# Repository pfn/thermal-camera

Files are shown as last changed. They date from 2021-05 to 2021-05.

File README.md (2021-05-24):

# DIY Thermal Camera #

This is a simple thermal camera that can be built using off-the-shelf parts
from Adafruit (albeit with a long lead time due to component shortages).

[Reddit post about it](https://www.reddit.com/r/functionalprint/comments/nfmj6n/diy_thermal_camera/)

## BOM ##

* [Adafruit 1.3" PiTFT Bonnet](https://www.adafruit.com/product/4506)
* [Raspberry Pi Zero W](https://www.adafruit.com/product/3400)
  * You'll want with headers if you don't have any you can solder yourself
* [MLX90640 IR Thermal Camera](https://www.adafruit.com/product/4407)
* [MicroSD card](https://www.adafruit.com/product/2820)
* [StemmaQT cable](https://www.adafruit.com/product/4210)

## Features ##

* Auto-start at boot
  * This software runs on a Raspberry Pi Zero W, as a result it needs to boot.
    When it boots, it automatically starts up via systemd
* Freeze frame
  * Pause capturing to examine the current frame, all view settings can be
    manipulated to look at individual pixel temperatures, adjust corrections,
    scales, etc.
* Capture to PNG
  * Saves images to `~pi/thermal-images`
* MTP support for transferring images
  * Exposes `~pi/thermal-images` over MTP for Windows,
    macOS (Android File Transfer) and Linux machines
* Selectable temperature ranges
  * Available temperature ranges are: auto-range (min, max),
    outdoor body detection (10-32C), indoor body detection (20-32C), hot spot
    identification (20-50C), and extremes (-10 - 200C)
* Switchable C/F temperature scale
* Adjustable emissivity correction
  * Adjustable from 0.05 to 1.00 in 0.05 increments. Default at 0.95
* Movable reticle showing temperature under the crosshairs
* Four lockable reticle points for indicating temperature
  * Temperature at 7 points can be tracked in real time: under the reticle, at
    the four locked reticle points, and the min and max points
* Switchable color range (Gnuplot PM3D, and a basic rainbow)
* Display of estimated ambient temparture
  * This can be warmer than ambient, depending on the temperature of the Pi
    inside the case.

### Controls ###

* Hold A (left button) and then B (right) together at the same time to exit
* Hold B and then A together at the same time to change the scale palette
  to PM3D or rainbow
* Press A by itself to freeze-frame, press again to release freeze-frame
* Press B by itself to toggle the temperature units between C and F
* Press U(p), L(eft), R(ight), D(own) by themselves to move the center reticle
* Hold B and press U to adjust emissivity correction up by 0.05
* Hold B and press D to adjust emissivity correction down by 0.05
* Hold B and press L or R to scroll through temperature ranges
* Press C(enter) by itself to lock a reticle location for temperature readout
* Hold B and press C to clear all selected reticle locations
* Hold A and press C to save the current screen to disk as PNG

## Instructions ##

This solution involves installing software from raspbian packages, python3
packages using `venv` and `pip`, and some locally compiled components
[uMTP-Responder](https://github.com/viveris/uMTP-Responder)

In addition to software, there is minimal hardware assembly and 3D printed
parts.

### Software ###

* $ `sudo apt install python3-venv`
* $ `python3 -m venv --system-site-packages ~/src/thermal-imaging`
* $ `cd ~/src && git clone https://github.com/pfn/thermal-camera thermal-imaging`
* $ `cd ~/src/thermal-imaging/bin`
* $ `./pip install ST7789`
* $ `./pip install mlx90640-driver`
* $ `./pip install mlx90640-driver-devicetree`
* $ `./pip install colour`
* $ `./pip install pillow`
* $ `./pip install RPi.GPIO`
* $ `sudo mkdir /etc/umtprd`
* $ `sudo cp ../conf/umtprd.conf /etc/umtprd/`
* $ `sudo cp ../conf/thermal-camera.service /etc/systemd/system/`
* $ `sudo cp ../conf/umtp-responder.service /etc/systemd/system/`
* $ `ln -s armv7l ../lib/python3.7/site-packages/mlx90640/libs/armv6l`
* $ `ln -s armv7l ../lib/python3.7/site-packages/mlx90640_devicetree/libs/armv6l`
* $ `cd ~/src && git clone https://github.com/viveris/uMTP-Responder`
* $ `cd uMTP-Responder && make`
* Add `dtoverlay=dwc2` to the bottom of `/boot/config.txt`
* $ `sudo systemctl enable thermal-camera`
* $ `sudo systemctl enable umtp-responder`
* Reboot the Pi

For any missing packages, `sudo apt install` them as appropriate.

### Hardware ###

Print 2x of the buttons, 4x of the spacers, the top and bottom of the case.

Solder headers onto the Pi if necessary.

Attach the StemmaQT cable to the camera and TFT bonnet.

Place the Pi into the bottom of the case. And place the 4 spacers onto the
nubs that protrude through the Pi.

Press the TFT bonnet down into place onto the Pi.

Position the camera on the bottom of the case and place the lens through the
hole.

Put the top of the case onto a flat surface, and put the buttons into the
button holes.

Run a bead of super glue around the edges and press the case together.

All done!

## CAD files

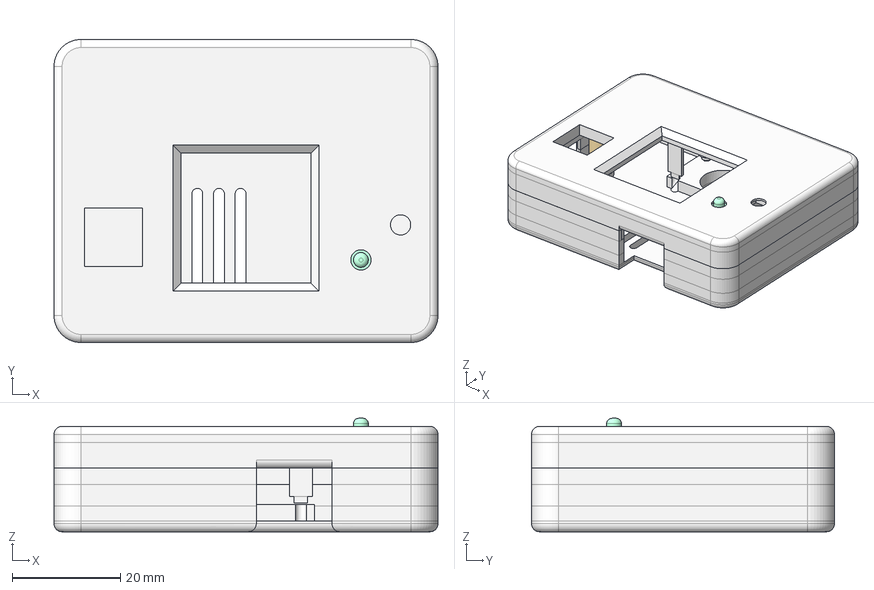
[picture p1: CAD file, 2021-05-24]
CAD/Case Design.step
71.0 x 56.0 x 21.0 mm
Top
Bottom
Standoffs
Buttons

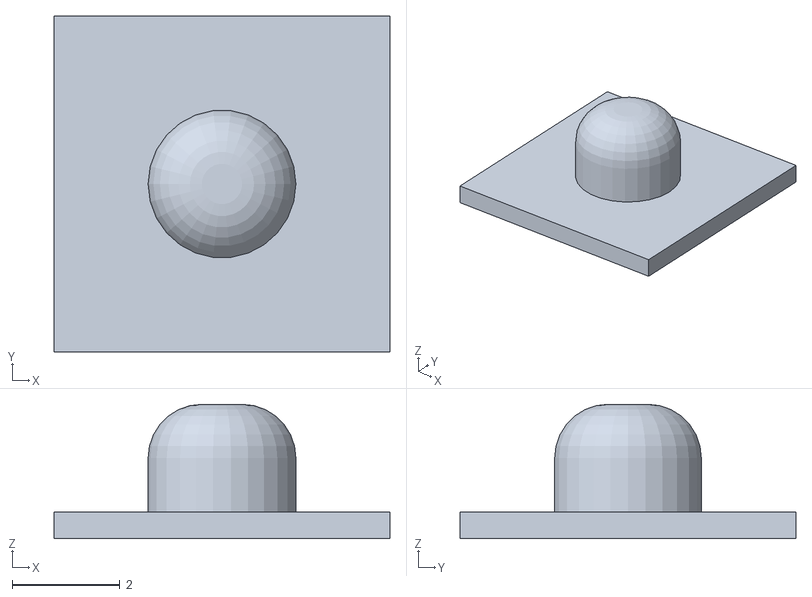
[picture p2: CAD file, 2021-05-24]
models/Button.stl
6.25 x 6.25 x 2.50

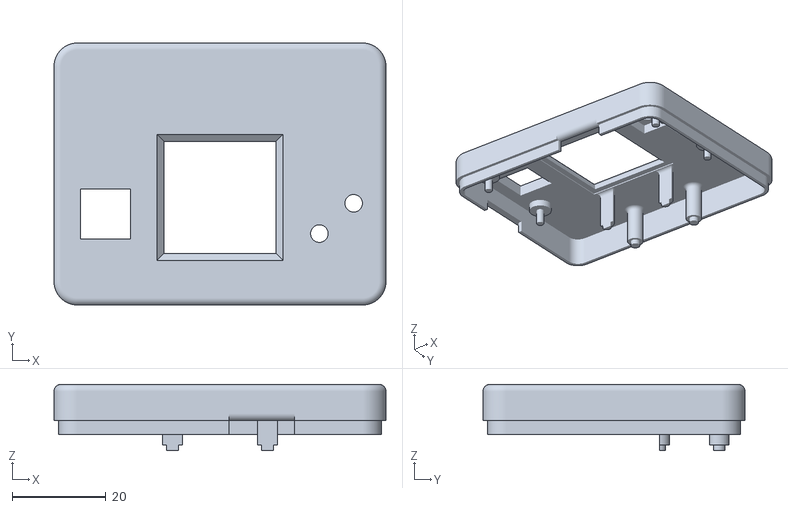
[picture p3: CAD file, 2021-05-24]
models/Case Top.stl
71.0 x 56.0 x 14.2

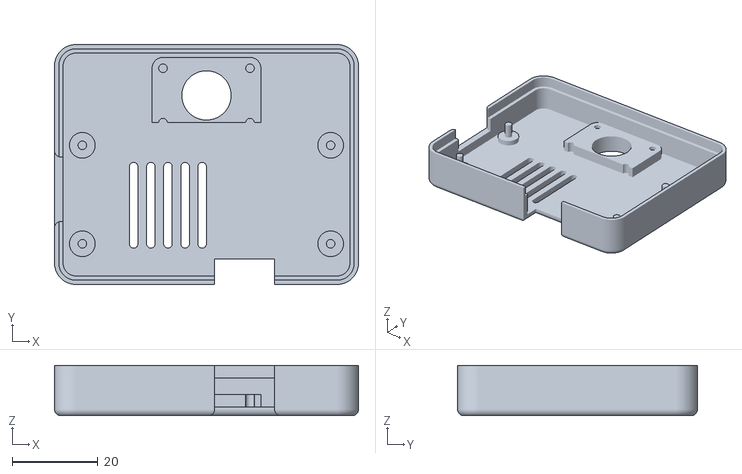
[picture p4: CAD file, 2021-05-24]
models/Case Bottom.stl
71.0 x 56.0 x 11.8

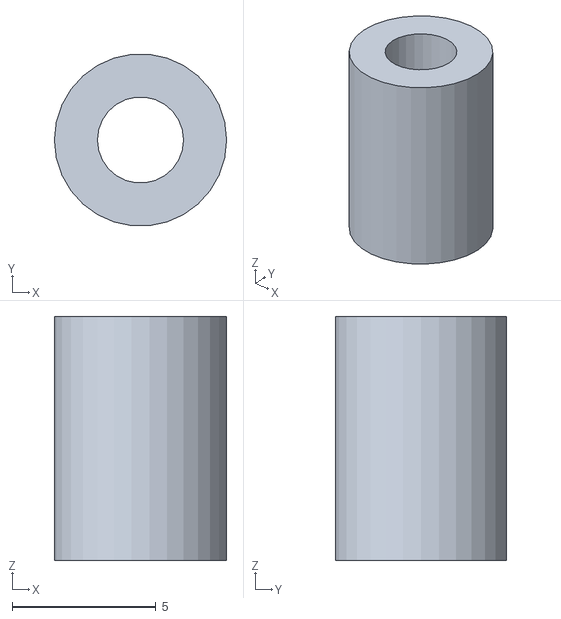
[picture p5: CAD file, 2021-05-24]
models/Standoff.stl
6.00 x 5.97 x 8.50

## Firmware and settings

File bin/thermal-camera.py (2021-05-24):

#!/home/pi/src/thermal-imaging/bin/python

save_path = "/home/pi/thermal-images"

# Imports take a while to execute, so interleave them as used
import os

import ST7789 as ST7789
disp = ST7789.ST7789(
  port=0,
  cs=ST7789.BG_SPI_CS_BACK,  # BG_SPI_CS_BACK or BG_SPI_CS_FRONT
  dc=25,
  backlight=26,               # 18 for back BG slot, 19 for front BG slot.
  spi_speed_hz=80 * 1000 * 1000,
  offset_left=0
)
disp.begin()
width = disp.width
height = disp.height

from PIL import Image, ImageDraw, ImageFont
image = Image.new("RGB", (width, height))
draw = ImageDraw.Draw(image)

def clear_screen(f=(0, 0, 0)):
    draw.rectangle((0, 0, width, height), outline=f, fill=f)
    disp.display(image)

clear_screen((0, 255, 255))

font_name = "/usr/share/fonts/truetype/dejavu/DejaVuSans.ttf"
FH = 16
fnt = ImageFont.truetype(font_name, FH)
caretfnt = ImageFont.truetype(font_name, FH * 2)
WHITE = (255, 255, 255)
line_number = 0

def init_text(text):
    global line_number
    draw.text((5, 5 + line_number * (FH + 2)), text, font=fnt, fill=WHITE)
    line_number += 1
    disp.display(image)

clear_screen()
init_text("Display initialized")

import RPi.GPIO as GPIO

import mlx90640
dev = mlx90640.MLX90640()
dev.i2c_init("/dev/i2c-1")
dev.set_refresh_rate(4)

init_text("Camera found")

# auto, FLIR default, indoor mammals, hot spots, extremes
ranges = ((0.0, 0.0), (10.0, 32.22),
        (20.0, 32.0), (20.0, 50.0), (-10.0, 200.0))

# globals used by button_press callback
freeze_frame = False
temp_range = 0
chordA = False
chordB = False
isF = False
emissivity = 0.95 # emissivity correction
reticle = int(768 / 2 - 16)
selected = list() 

import re
file_pattern = re.compile(r"image(\d{4}).png")

import functools
flatmap = lambda f, xs: [y for ys in xs for y in f(ys)]

def image_ordinal(f):
    if not os.path.isfile(os.path.join(save_path, f)):
        return ()
    m = re.match(file_pattern, f)
    return [int(m.group(1))] if m is not None else ()

def next_ordinal():
    return max([0] +
            [x for x in flatmap(image_ordinal, os.listdir(save_path))]) + 1

def save_image():
    global saving
    global is_dirty
    os.makedirs(save_path, exist_ok=True)
    saving = True
    is_dirty = False
    image.save("%s/image%04d.png" % (save_path, next_ordinal()))
    saving = False

colors = []
scale = []

# button pin assignments
A = 5
B = 6
L = 27
R = 23
U = 17
D = 22
C = 4
def button_press(x):
    global chordA
    global chordB
    global isF
    global emissivity
    global reticle
    global selected
    global temp_range
    global freeze_frame
    global is_dirty
    global scale
    global colors

    if not (x == A and chordA or x == B and chordB):
        is_dirty = True

    if x == A and not chordA:
        if GPIO.input(B) == 0:
            chordB = True
            colors = pm3d_colors if colors is not pm3d_colors else rainbow_colors
            scale = pm3d_scale if scale is not pm3d_scale else rainbow_scale
        else:
            freeze_frame = not freeze_frame
    else:
        chordA = False

    if x == B and not chordB:
        if GPIO.input(A) == 0:
            chordA = True
            clear_screen()
            disp.set_backlight(0)
            exit()
        else:
            isF = not isF
    else:
        chordB = False

    if x == U:
        if GPIO.input(B) == 0:
            chordB = True
            emissivity = min(emissivity + 0.05, 1.00)
        else:
            reticle = max(reticle - 32, 0)
    if x == D:
        if GPIO.input(B) == 0:
            chordB = True
            emissivity = max(emissivity - 0.05, 0.05)
        else:
            reticle = min(reticle + 32, 768)
    if x == L:
        if GPIO.input(B) == 0:
            temp_range = max(0, temp_range - 1)
            chordB = True
        else:
            reticle = min(reticle + 1, 768)
    if x == R:
        if GPIO.input(B) == 0:
            temp_range = min(len(ranges) - 1, temp_range + 1)
            chordB = True
        else: 
            reticle = max(reticle - 1, 0)
    if x == C:
        if GPIO.input(B) == 0:
            chordB = True
            if freeze_frame:
                # capture image to disk
                pass
            else:
                selected = []
        elif GPIO.input(A) == 0:
            chordA = True
            save_image()
        else:
            if reticle in selected:
                selected.remove(reticle)
            else:
                selected.append(reticle)
            while len(selected) > 4:
                del selected[0]

GPIO.setmode(GPIO.BCM)
for pin in [A, B, L, R, U, D, C]:
    GPIO.setup(pin, GPIO.IN)
    GPIO.add_event_detect(pin, GPIO.RISING)
    GPIO.add_event_callback(pin, button_press)

init_text("Buttons configured")

import math
def pm3d(steps):
    def _pm3d(x):
        r = round(255 * math.sqrt(x))
        g = round(255 * math.pow(x, 3))
        b = round(255 * max(math.sin(2 * math.pi * x), 0))
        return (int(r) | int(g) << 8 | int(b) << 16)
    return [x for x in map(lambda _x: _pm3d(_x / steps), range(0, steps))]

from colour import Color
rainbow_colors = list(Color('indigo').range_to(Color('red'), 256))
rainbow_colors = [(int(c.red * 255) | int(c.green * 255) << 8 |
    int(c.blue * 255) << 16) for c in rainbow_colors]
pm3d_colors = pm3d(256)

rainbow_scale = list(Color('red').range_to(Color('indigo'), 144 - 2 * FH - 4))
rainbow_scale = [(int(c.red * 255) | int(c.green * 255) << 8 |
    int(c.blue * 255) << 16) for c in rainbow_scale]

pm3d_scale = pm3d(144 - 2 * FH - 4)
pm3d_scale.reverse()

scale = pm3d_scale
colors = pm3d_colors

init_text("Palettes initialized")

def is_autorange():
    return ranges[temp_range][0] == ranges[temp_range][1]

def range_max(n):
    return n if is_autorange() else ranges[temp_range][1]

def range_min(n):
    return n if is_autorange() else ranges[temp_range][0]

def draw_scale(draw, min_temp, max_temp):
    for (r,x) in enumerate(scale):
        draw.line((8, r + FH + 2, 24, r + FH + 2), fill=x)

    # scale
    draw.text((0, 0), "%.1f\u00b0" % display_unit(range_max(max_temp)),
            font=fnt, fill=WHITE)
    draw.text((0, 144 - FH), "%.1f\u00b0" % display_unit(range_min(min_temp)),
            font=fnt, fill=WHITE)


P = 6 # pixel sampling size

subscripts = ["\u2081", "\u2082", "\u2083", "\u2084", "\u2085", "\u2086"]
def draw_reticle(draw):
    for (i,r) in enumerate(selected):
        y = r / 32
        x = r % 32
        draw.line((P * (31 - x) + 48, P * y + 6,
            P * (31 - x) + P + 48, P * y + 6),
                fill=WHITE)
        draw.line((P * (31 - x) + 48 + 6, P * y,
            P * (31 - x) + 48 + 6, P * y + P),
                fill=WHITE)
        draw.line((P * (31 - x) + 48, P * y,
            P * (31 - x) + P + 48, P * y),
                fill=WHITE)
        draw.line((P * (31 - x) + 48, P * y,
            P * (31 - x) + 48, P * y + P),
                fill=WHITE)
        draw.text((P * (31 - x) + 48 + P, P * y - P / 2),
                subscripts[i], font=fnt, fill=WHITE)
    y = reticle / 32
    x = reticle % 32
    draw.line((P * (31 - x) + 48, P * y + 3, P * (31 - x) + P + 48, P * y + 3),
            fill=WHITE)
    draw.line((P * (31 - x) + 48 + 3, P * y, P * (31 - x) + 48 + 3, P * y + P),
            fill=WHITE)

def draw_minmax(min_pt, max_pt):
    for (i, p) in enumerate((min_pt, max_pt)):
        y = p / 32
        x = p % 32
        draw.text((P * (31 - x) + 48 - FH / 4, P * y - FH / 2),
                "\u02c5" if i == 0 else "\u02c4", font=caretfnt,
                fill=WHITE if i == 0 else (50, 50, 50))

selected_locations = [(0, 204), (0, 224), (120, 204), (120, 224)]

def draw_selected(draw, frame):
    for i in range(0, len(selected)):
        draw.text(selected_locations[i], "+%s = %.1f\u00b0" %
                (subscripts[i], display_unit(frame[selected[i]])),
                font=fnt, fill=WHITE)

def display_unit(measurement):
    if not isF:
        return measurement
    else:
        return (measurement * 9/5) + 32

def clamp(x, in_min, in_max):
    return max(in_min, min(x, in_max))

def map_value(x, in_min, in_max, out_min, out_max):
    return int((clamp(x, in_min, in_max) - in_min) * (out_max - out_min) /
            (in_max - in_min) + out_min)

is_dirty = True
saving = False
def freeze_frame_status():
    marker = "\u03a3" if saving else ("*" if is_dirty else "\u2713")
    draw.text((width - FH, height - FH), marker, font=fnt, fill=WHITE)

def analyze_px(acc, px):
    min_temp = min(acc[0], px[1])
    max_temp = max(acc[1], px[1])
    min_pt = px[0] if min_temp != acc[0] else acc[2]
    max_pt = px[0] if max_temp != acc[1] else acc[3]
    return (min_temp, max_temp, min_pt, max_pt)

def render(frame, ta):
    (min_temp, max_temp, min_pt, max_pt) = functools.reduce(
            analyze_px, enumerate(frame), (999, -999, 0, 0))
    pixels = list(map(lambda x: colors[map_value(x,
        range_min(min_temp), range_max(max_temp), 0, len(colors) - 1)], frame))

    for x in range(0, 32):
        for y in range(0, 24):
            c = pixels[y * 32 + x]
            draw.rectangle((
                (31 - x) * P + 48,
                y * P,
                (31 - x) * P + P + 48,
                y * P + P
                ), outline=c, fill=c)
    # clear the bottom box
    draw.rectangle((0, 144, 240, 240), outline=0, fill=0)
    # clear the vertical column
    draw.rectangle((0, 0, 48, 240), outline=0, fill=0)

    #draw.text((120, 152), "\u03b5 = %0.2f" % emissivity, font=fnt, fill=WHITE)
    draw.text((96, 152), "Ta = %.1f\u00b0" % display_unit(ta),
            font=fnt, fill=WHITE)

    draw.text((200, 152), "\u00b0 = %s" % ("F" if isF else "C"),
            font=fnt, fill=WHITE)
    draw.text((0, 152), "+ = %.1f\u00b0" % display_unit(frame[reticle]),
            font=fnt, fill=WHITE)
    #draw.text((0, 172), "Ta = %.1f\u00b0" % display_unit(ta),
    #        font=fnt, fill=WHITE)
    draw.text((0, 172), "\u03b5 = %0.2f" % emissivity, font=fnt, fill=WHITE)
    draw.text((84, 172), "%.1f\u00b0 < T < %.1f\u00b0" %
            (display_unit(min_temp), display_unit(max_temp)),
            font=fnt, fill=WHITE)

    draw_scale(draw, min_temp, max_temp)
    draw_reticle(draw)
    draw_minmax(min_pt, max_pt)
    draw_selected(draw, frame)

# fetch and apply parameters
dev.dump_eeprom()
init_text("EEPROM settings fetched")
dev.extract_parameters()

init_text("Camera parameters applied")

wait_for_valid = 0
while True:

    try:
        dev.get_frame_data()
        ta = dev.get_ta() - 8.0 # ambient adjustment
        frame = dev.calculate_to(emissivity, ta)
        if wait_for_valid < 2:
            if wait_for_valid == 0:
                init_text("Waiting for valid data...")
            wait_for_valid += 1
            continue
        render(last_frame if freeze_frame else frame,
                last_ta if freeze_frame else ta)
        if not freeze_frame:
            last_frame = frame
            last_ta = ta
            is_dirty = True
            saving = False
        else:
            freeze_frame_status()
        disp.display(image)

    except ValueError as err:
        # these happen, no biggie - retry
        print("Got an error: %s" % err)
        continue
